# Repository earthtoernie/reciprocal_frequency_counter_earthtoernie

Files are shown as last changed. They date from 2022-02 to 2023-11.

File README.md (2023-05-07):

# Reciprocal frequency counter for Raspberry pi pico

Shield: [][cc-by-sa]

This work is licensed under a
[Creative Commons Attribution-ShareAlike 4.0 International License][cc-by-sa].

[][cc-by-sa]

[cc-by-sa]: http://creativecommons.org/licenses/by-sa/4.0/
[cc-by-sa-image]: https://licensebuttons.net/l/by-sa/4.0/88x31.png
[cc-by-sa-shield]: https://img.shields.io/badge/License-CC%20BY--SA%204.0-lightgrey.svg

## Citation
[Rrciprocal frequency counter](https://forums.raspberrypi.com/viewtopic.php?t=306250)
 The guts of the "pio" code was copied from this thread, and slightly modified and translated from "micropython"
 Display stuff, and PCB is my own.

## Main project
[The counter](pico_display_oled/main.cpp)

## Circuit board
[kicad board](kicad_pico_counter_new)
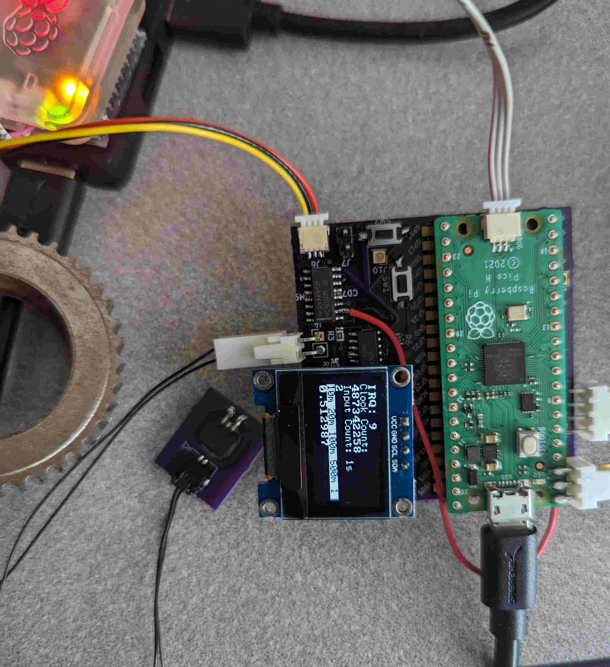
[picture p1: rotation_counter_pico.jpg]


## Background
- Wanted to make a speed sensor to detect gear teeth for some application. Did not need to use a "Reciprocal frequency counter" and / or such
a complicated "pio" setup, but decided to go down this route anyway.

- Picked a part from "Allegro microsystems" to do the sensing. There was no "Development board" available, but this should be just as good :)

- "ATS19480: Large Air Gap, GMR Speed Sensor IC for Gear Tooth Sensing" is the part. Should be available on Digikey or Mouser.

## Features
- Circuit board has a "driver" to read from a 2 terminal device. Window comparator added to translate discrete states of current, to 3.3 IO voltage.
This is for compatibility with GPIO on the pico board.

- Have had success using the sensor to read from the position 

- Button to change the window size

- Reset button (the pico board should have had this from the get go)

- Button to switch between sensor input, and input from 50ohm source (function generator)

## Brag
Was able to conveniently run from the 5V usb power source, with no additional boost converter.

## Awesome script to install sdk on Ubuntu 23.04
[install script](NOTES/install_raspberry_pico.sh) 

# Notes
Some other junk is included in this project (interfacing with other sensors), feel free to ignore. Also other "Scratch" projects included

sudo minicom -D /dev/ttyACM0 -b 115200  

Also examples from [pimoroni C examples](https://github.com/pimoroni/pimoroni-pico/tree/main/examples)  
how to setup IDE [Pico + cLion](https://forums.raspberrypi.com/viewtopic.php?t=310446)

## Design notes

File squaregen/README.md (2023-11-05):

do some stuff with [Pico board](https://github.com/Xinyuan-LilyGO/LILYGO-T-display-RP2040)

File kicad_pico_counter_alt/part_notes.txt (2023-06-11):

Parts:

IC's
1x, Mouser, TI, INA203AIDR, Unidir Msrmt Current Shunt Mon, Mouser 595-INA203AIDR
1x, Digikey, TI, TS5A63157DBVR, TS5A63157DBVR, IC SWITCH SPDT X 1 10OHM SOT23-6, 296-21194-1-ND
1x, Digikey, Raspberry Pi, SC0917, RASPBERRY PI PICO H, 2648-SC0917-ND
1x, Digikey, Microchip, 24AA64T-E/OT, IC EEPROM 64KBIT I2C SOT23-5m, 24AA64T-E/OTCT-ND
1x, Digikey, Nexperia, 74HC2G34GV 125, IC BUFFER NON-INVERT 6V 6TSOP, 1727-8398-1-ND
1x, Digikey, Allegro MicroSystems, ATS19580LSNBTN-FSNHPO-A, LARGE AIR GAP GMR TRANSMISSION, 620-ATS19580LSNBTN-FSNHPO-ADKR-ND

SMT connectors
1x, Digikey, JST, SM03B-SRSS-TB(LF)(SN), CONN HEADER SMD R/A 3POS 1MM, 455-1803-1-ND
1x, Digikey, JST, SM04B-SRSS-TB(LF)(SN), CONN HEADER SMD R/A 4POS 1MM, 455-1804-1-ND

RF connectors
1x, Digikey, Molex, 0733960320, SMB Connector Jack, SMB 50 OHM JACK R/A PCB, 900-0733960320-ND

thru hole connectors,
2x, Digikey, Samtec, SLW-120-01-F-S, CONN RCPT 20POS 0.1 GOLD PCB, SAM12857-ND
2x, Digikey, Molex, 0022122024, CONN HEADER R/A 2POS 2.54MM, WM2711-ND
1x, Digiket, Molex, 0022122044, CONN HEADER R/A 4POS 2.54MM, WM2713-ND
1x, Digikey, Sullins Connector Solutions, PPPC041LFBN-RC, CONN HDR 4POS 0.1 GOLD PCB, S7037-ND

alterntive
1x, Digikey, Adafruit, 5585, SHORT SOCKET HEADERS FOR RASPBER, 1528-5585-ND

Switches
4x, Digikey, C&K, PTS636 SL50 SMTR LFS, TACT 6.0 X 3.5, 5.0 MM H 130GF, CKN12313-1-ND
1x, Digikey, C&K, RS-282G05A3-SM RT, SWITCH TACTILE SPST-NO 0.05A 12V, CKN10384CT-ND

passives
2x, Digikey, Walsin Technology Corporation, WR08X332 JTL, RES 3.3K OHM 5% 1/8W 0805, 1292-WR08X332JTLCT-ND
1x, Digikey, Stackpole Electronics Inc, RNCP0805FTD49R9, RES 49.9 OHM 1% 1/4W 0805, RNCP0805FTD49R9CT-ND
1x, Digikey, Stackpole Electronics Inc, RMCF0805ZT0R00, RES 0 OHM JUMPER 1/8W 0805, RMCF0805ZT0R00CT-ND
1x, Digikey, Delta Electronics/Cyntec, RLT1220-F-5R00-FNH, RES SMD 5 OHM 1% 1/3W 0805, 2037-RLT1220-F-5R00-FNHCT-ND
1x, Digikey, TDK Corporation, CGA4J3X7R1A335K125AB, CAP CER 3.3UF 10V X7R 0805,445-12729-1-ND
1x, Digikey, Samsung Electro-Mechanics, CL21B105KOFNNNE, CAP CER 1UF 16V X7R 0805, 1276-1026-1-ND
1x, Digikey, Samsung Electro-Mechanics, CL21B103KBANNNC, CAP CER 10000PF 50V X7R 0805, 1276-1015-1-ND

misc connectors and parts
Digikey, Molex, 5037630291, CONN HEADER SMD R/A 2POS 1MM, WM10654CT-ND
Digikey, Molex, 0151310206, CABLE-ASSY PICOLOCK 2 CIRCUIT 60, WM16704-ND
Digikey, Harwin Inc, M20-9993645, CONN HEADER VERT 36POS 2.54MM, 952-2272-ND
Digikey, Harwin Inc, M20-9773642, CONN HEADER VERT 36POS 2.54MM, 952-2848-ND
Digikey, Molex, 0008650816, CONN 22-30AWG CRIMP GOLD, WM6391-ND,
Digikey, Molex, 0022013047, CONN RCPT HSG 4POS 2.54MM, WM2002-ND
Digikey, Molex, 0022013027, CONN RCPT HSG 2POS 2.54MM, 900-0022013027-ND
Digikey, Keystone Electronics, 5007, PC TEST POINT COMPACT WHITE, 36-5007-ND
Digikey, Taoglas Limited, CAB.0101, CBL ASSY SMA-SMB JACK-PLG 3.937", 931-1104-ND
Digikey, CNC Tech, 10368-28-1-0500-002-1-TS, HOOK-UP STRND 28AWG 300V WHT 25', CN390W-25-ND
Digikey, Sullins Connector Solutions, PRPC040SACN-RC, CONN HEADER VERT 40POS 2.54MM, S1131EC-40-ND
Digikey, Molex, 0022012091, CONN RCPT HSG 9POS 2.54MM, 23-0022012091-ND

tools
1x, Digikey, Apex Tool Group, T0050104199, RTP 004 S TIP CHISEL 0.4X0.2, 72-T0050104199-ND
1x, Digikey, Apex Tool Group, T0052922699, WXPP HANDPIECE FOR RTP TIP, 72-T0052922699-ND
1x, Digikey, Apex Tool Group, WX2N, SOLDERING STATION 200W 2 CH, 120V WX2N-ND
1x, Digikey, Apex Tool Group, T0050105899, RTU 015 S MS TIP CHISEL 1.5X0.4, 72-T0050105899-ND
1x, Digikey, Apex Tool Group, T0052923099, WXUP MS HANDPIECE FOR RTU MS TIP, 72-T0052923099-ND
1x, Digikey, Molex, 0638170000, TOOL HAND STRIPPER 8-34AWG, WM9969-ND
1x, Digikey, Molex, 0638118200, TOOL HAND CRIMPER 22-30AWG SIDE, WM9019-ND

1x, Digikey, Jonard Tools, EX-2, TOOL EXTRACTOR IC DIP 24-40PIN, K158-ND (to remove pico from socket)

notes about parts

*for EEPROM:
Most "Microchip" parts set lower address bits to "don't care's" which is not desirable
need a  SOT-23-5 part where the address pins are set internally to "0" so use:

24AA64/24FC64/24LC64 (24AA64T-E/OT seems to be in stock frequently) or
24AA64F/24LC64F/24FC64F

only difference is write protect scheme, but write protect is not used anyway (tied to ground)

alternatively "SparkFun Qwiic EEPROM Breakout - 512Kbit" can be used, or no EEPROM chip (state not saved)

*for buffer / level converter:
Nexperia 74HC2G34GV,125 used because of small board size
TI CD74HC4050M96 also tested, but changed due to large board size

*for current sense / comparator, 
INA203AIDR, stocked at Mouser, but not Digikey
INA203AID also works (same thing) but seems to be even less stocked

molex connectors, board:
Molex 0022122024, CONN HEADER R/A 2POS 2.54MM, WM2711-ND

smb connector:
Molex 0733960320, SMB 50 OHM JACK R/A PCB, 900-0733960320-ND

JST connectors:

connectors for sensor:
Molex 5037630291 WM10654CT-ND
Molex 0151310206 WM16704-ND

tact switch:
C&K PTS636 SL50 SMTR LFS, CKN12313-1-ND

(use different reset switch)
https://www.digikey.com/en/products/detail/c-k/RS-282G05A3-SM-RT/2747190

IC switch:
TI TS5A63157DBVR, IC SWITCH SPDT X 1 10OHM SOT23-6, 296-21194-1-ND
https://www.digikey.com/en/products/detail/texas-instruments/TS5A63157DBVR/1216800

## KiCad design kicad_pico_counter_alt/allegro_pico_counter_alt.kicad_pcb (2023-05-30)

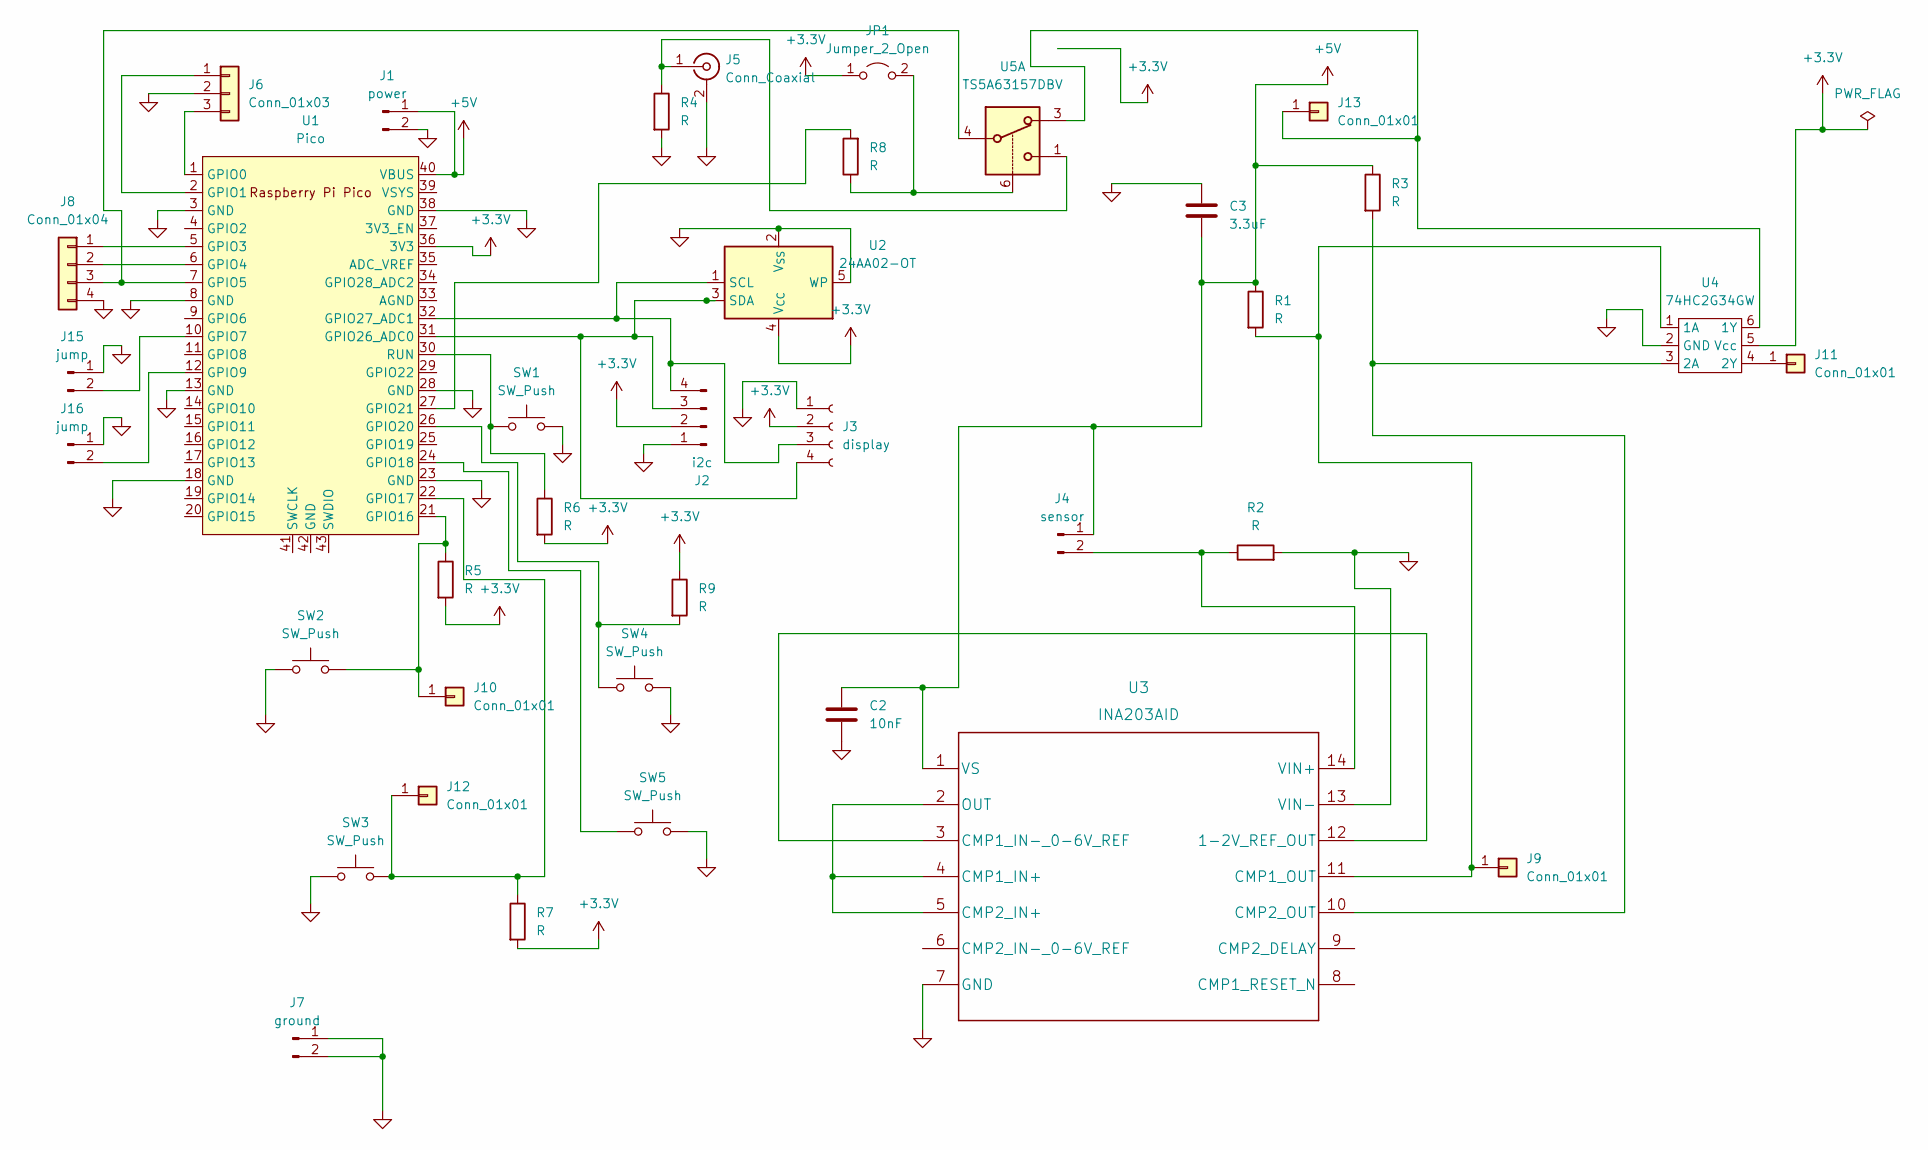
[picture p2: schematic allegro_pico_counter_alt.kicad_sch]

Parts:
C2: 10nF; C_0805_2012Metric
C3: 3.3uF; C_0805_2012Metric
J1: power; PinHeader_1x02_P2.54mm_Vertical
J2: i2c; JST_SH_SM04B-SRSS-TB_1x04-1MP_P1.00mm_Horizontal
J3: display; PinHeader_1x04_P2.54mm_Vertical
J4: sensor; PinHeader_1x02_P2.54mm_Vertical
J5: Conn_Coaxial; SMB_Jack_Vertical
J6: Conn_01x03; JST_SH_SM03B-SRSS-TB_1x03-1MP_P1.00mm_Horizontal
J7: ground; PinHeader_1x02_P2.54mm_Vertical
J8: Conn_01x04; PinHeader_1x04_P2.54mm_Vertical
J9, J10, J11, J12, J13: Conn_01x01; PinHeader_1x01_P2.54mm_Vertical
J15, J16: jump; PinHeader_1x02_P2.54mm_Vertical
JP1: Jumper_2_Open; PinHeader_1x02_P2.54mm_Vertical
R1, R2, R3, R4, R5, R6, R7, R8, R9: R; R_0805_2012Metric
SW1, SW2, SW3, SW4, SW5: SW_Push; SW_SPST_CK_RS282G05A3
U1: Pico; RPi_Pico_SMD_TH
U2: 24AA02-OT; SOT-23-5
U3: INA203AID
U4: 74HC2G34GW; SOT-363_SC-70-6_Handsoldering
U5: TS5A63157DBV; SOT-23-6

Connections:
+3.3V: J2.2, J3.2, JP1.1 (A), R5.2, R6.2, R7.2, R9.1, U1.36 (3V3), U2.4 (V_{CC}), U4.5 (Vcc); also elsewhere on the board
+5V: C2.1, C3.2, J1.1, J4.1, R1.1, R3.1, U1.40 (VBUS), U3.1 (VS)
GND: C2.2, C3.1, J1.2, J2.1, J3.1, J5.2 (Ext), J6.2, J7.1, J7.2, J8.4, J15.1, J16.1, R2.2, R4.2, SW1.2, SW2.1, SW3.1, SW4.2, SW5.2, U1.3 (GND), U1.8 (GND), U1.13 (GND), U1.18 (GND), U1.23 (GND), U1.28 (GND), U1.38 (GND), U2.2 (V_{SS}), U2.5 (WP), U3.7 (GND), U3.13 (VIN-), U4.2 (GND)
unnamed 3: J2.3, J3.4, U1.31 (GPIO26_ADC0), U2.3 (SDA); also elsewhere on the board
unnamed 4: J2.4, J3.3, U1.32 (GPIO27_ADC1), U2.1 (SCL); also elsewhere on the board
unnamed: J4.2, R2.1, U3.14 (VIN+)
unnamed: J5.1 (In), R4.1, U5.1
unnamed: J6.1, U1.2 (GPIO1)
unnamed: J6.3, U1.1 (GPIO0)
unnamed: J8.1, U1.5 (GPIO3)
unnamed: J8.2, U1.6 (GPIO4)
unnamed: J8.3, U1.7 (GPIO5), U5.4
unnamed: J9.1, R1.2, U3.11 (CMP1_OUT), U4.1 (1A)
unnamed: J10.1, R5.1, SW2.2, U1.21 (GPIO16)
unnamed: J11.1, U4.4 (2Y)
unnamed: J12.1, R7.1, SW3.2, U1.22 (GPIO17)
unnamed: J13.1, U4.6 (1Y), U5.3
unnamed: J15.2, U1.10 (GPIO7)
unnamed: J16.2, U1.12 (GPIO9)
unnamed: JP1.2 (B), R8.1, U5.6
unnamed: SW5.1, U1.24 (GPIO18)
unnamed: R9.2, SW4.1, U1.26 (GPIO20)
unnamed: R8.2, U1.27 (GPIO21)
unnamed: R6.1, SW1.1, U1.30 (RUN)
unnamed: U3.3 (CMP1_IN-_0-6V_REF), U3.12 (1-2V_REF_OUT)
unnamed: U3.2 (OUT), U3.4 (CMP1_IN+), U3.5 (CMP2_IN+)
unnamed: R3.2, U3.10 (CMP2_OUT), U4.3 (2A)

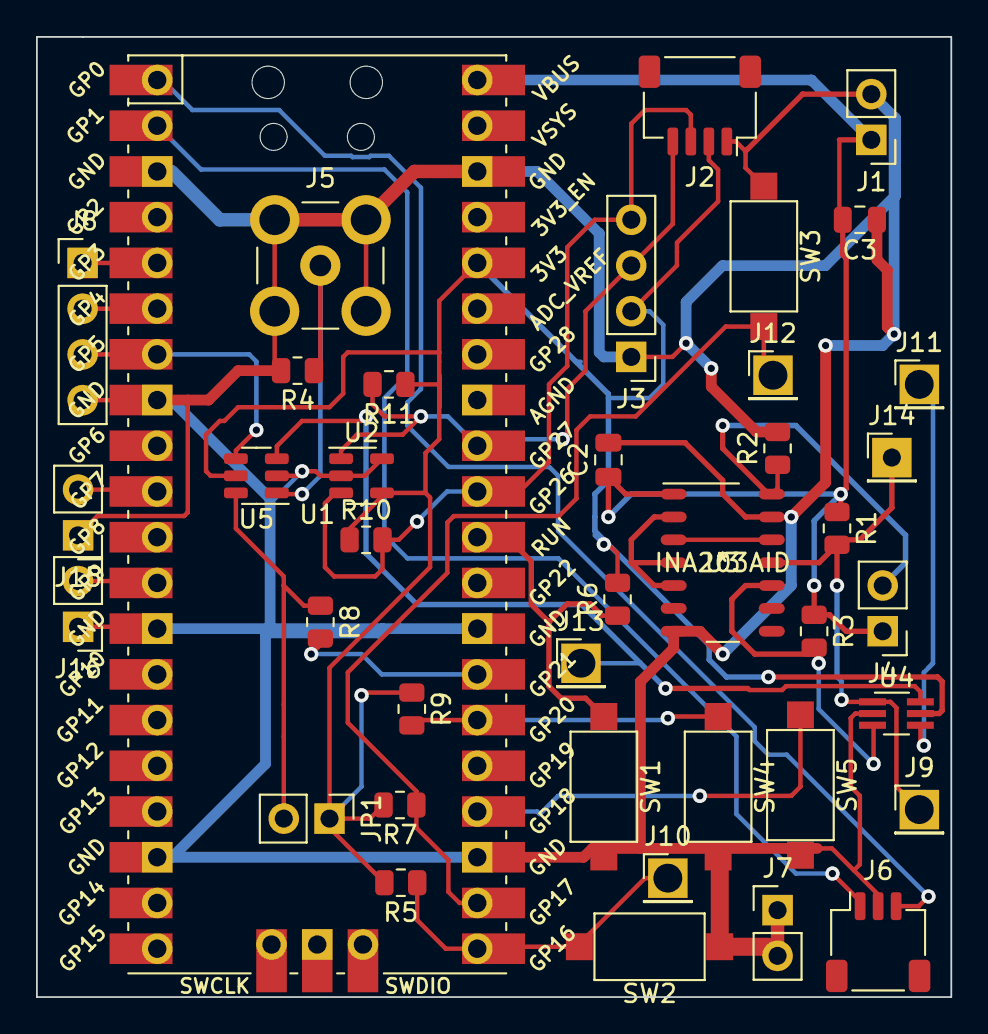
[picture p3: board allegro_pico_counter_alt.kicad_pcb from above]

Board: 2 copper layers, 50.8 x 53.3 mm, 40 parts (0 on the bottom side), 27 nets.

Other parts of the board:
J14: Conn_01x01; PinHeader_1x01_P2.54mm_Vertical
R10, R11: R; R_0805_2012Metric

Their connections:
+3.3V: R10.1, R11.1; also elsewhere on the board
unnamed 3: R10.2; also elsewhere on the board
unnamed 4: R11.2; also elsewhere on the board

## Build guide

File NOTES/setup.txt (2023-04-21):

install:

openocd
(sdk deps)
cmake gcc-arm-none-eabi gcc g++
(uart deps)
minicom

in pico folder:

main SDK:
git clone https://github.com/raspberrypi/pico-sdk.git
cd pico-sdk
git submodule update --init
cd ..

add to bashrc:
export PICO_SDK_PATH=/home/ernie/pico/pico-sdk
export PICO_EXAMPLES_PATH=/home/ernie/pico/pico-examples
export PICO_EXTRAS_PATH=/home/ernie/pico/pico-extras
export PICO_PLAYGROUND_PATH=/home/ernie/pico/pico-playground

git clone https://github.com/raspberrypi/pico-examples.git
git clone https://github.com/raspberrypi/pico-extras.git
git clone https://github.com/raspberrypi/pico-playground.git

inside of pico examples:
mkdir build
cd build
cmake ../ -DCMAKE_BUILD_TYPE=Debug

build some examples
cd blink
make
cd ..

cd hello_world
make
cd ..

MUST INSTALL... sudo apt install pkg-config
needed for picotool: libusb-1.0-0-dev
apt install 
build pictotool::
git clone https://github.com/raspberrypi/picotool.git
cd picotool
mkdir build
cd build
cmake ../
make
sudo cp picotool /usr/local/bin/

=============
see https://datasheets.raspberrypi.com/pico/getting-started-with-pico.pdf

code --install-extension marus25.cortex-debug
code --install-extension ms-vscode.cmake-tools
code --install-extension ms-vscode.cpptools

now onto fixing:
statics/globals/functions may not be properly classified:
https://forums.raspberrypi.com/viewtopic.php?t=333146
to actually get to run in the debugger in vscode...
sudo apt install gdb-multiarch 
sudo apt update
sudo apt install binutils-multiarch
cd /usr/bin
ln -s /usr/bin/objdump objdump-multiarch
ln -s /usr/bin/nm nm-multiarch

make sure to install Ninja!
sudo apt install ninja-build

https://github.com/microsoft/vscode-cmake-tools/blob/main/docs/debug-launch.md

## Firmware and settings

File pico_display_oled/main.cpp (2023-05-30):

#include <cstring>
#include <hardware/irq.h>
#include <cstdio>
#include <string>
#include "pico/stdio.h"
#include "pico/multicore.h"
#include "hardware/pio.h"
#include "count.pio.h"
#include "ss_oled.hpp"

#define INPUT_PIN 5
#define GATE_PIN 4
#define PULSE_FIN_PIN 3

// Button pins
#define BUTTON_WINDOW_PIN_16 16
#define BUTTON_SOURCE_PIN_17 17

// output pins
#define LED_PIN 25
// #define EXT50_EN_PIN 12
#define EXT50_EN_PIN 21

// i2c stuff. oled stuff
#define PICO_DEFAULT_I2C 1
#define PICO_DEFAULT_I2C_SDA_PIN 26
#define PICO_DEFAULT_I2C_SCL_PIN 27
#define PICO_I2C i2c_default
#define I2C_SPEED 400000

#define OLED_WIDTH 128
#define OLED_HEIGHT 64

#define GATE_err 0
#define GATE_1s 1
#define GATE_10ms 16
#define GATE_20ms 17
#define GATE_100ms 18
#define GATE_500ms 19

// global refference to display
extern picoSSOLED myOled(OLED_128x64, 0x3c, 0, 0, PICO_I2C, PICO_DEFAULT_I2C_SDA_PIN, PICO_DEFAULT_I2C_SCL_PIN, I2C_SPEED);


// debounce control
unsigned long time_window_state_debounce = to_ms_since_boot(get_absolute_time());
unsigned long time_source_state_debounce = to_ms_since_boot(get_absolute_time());

const int delayTime = 300; // Delay for every push button may vary

// glbal state ow windows in inputs
int button_window_state; // 1 represents the smallest window
bool button_source_state;

void update_source_state(bool is_external)
{
    if (is_external == true)
    {
        myOled.write_string(0, 0, 1, (char *)"50 Ohm, Clock Count:", FONT_6x8, 0, 1);
    }
    else
    {
        myOled.write_string(0, 0, 1, (char *)"Sensor, Clock Count:", FONT_6x8, 0, 1);
    }
    gpio_put(EXT50_EN_PIN, is_external);
    button_source_state = is_external; // update global state
}

void source_state_changed_callback(uint gpio, uint32_t events)
{
    if (gpio == BUTTON_WINDOW_PIN_16){
        if ((to_ms_since_boot(get_absolute_time()) - time_window_state_debounce) > delayTime){
            time_window_state_debounce = to_ms_since_boot(get_absolute_time());
            printf("********** WINDOW button pressed! %u\n", gpio);

            // Interrupt function lines
            // TODO
        }
    } else if (gpio == BUTTON_SOURCE_PIN_17){
        if ((to_ms_since_boot(get_absolute_time()) - time_source_state_debounce) > delayTime){
            time_source_state_debounce = to_ms_since_boot(get_absolute_time());
            printf("********** SOURCE button pressed! %u\n", gpio);
            update_source_state(!button_source_state);
        }
    }
}

uint32_t max_count = 4294967295;// const((1 << 32) - 1), highest unsigned int


PIO sd_pio = pio0;
volatile bool update_flag = false;
uint32_t countTo = 125000000; // 1M
int set_pin = 0;
uint32_t data [2] = { 0, 0 };



//https://raspberrypi.github.io/pico-sdk-doxygen/group__hardware__irq.html
void isr()
{
    pio_interrupt_clear(pio0, 0);
    //irq_clear(PIO0_IRQ_0);

    printf("IRQ: ");

    if(!update_flag){
        pio_sm_put(sd_pio, 0, countTo);
        pio_sm_exec(sd_pio, 0, pio_encode_pull(false, false));
        //printf("irq: ");

        data[0] = pio_sm_get(sd_pio, 1);
        data[1] = pio_sm_get(sd_pio, 2);
        update_flag = true;
    }
//    pio_interrupt_clear(pio0, 0);
//    pio_interrupt_clear(pio0, 0);
//    irq_clear(PIO0_IRQ_0);
}

void init_sm(uint32_t freq) {
    gpio_init(INPUT_PIN);
    gpio_init(GATE_PIN);
    gpio_init(PULSE_FIN_PIN);
    gpio_set_dir(INPUT_PIN, GPIO_IN);
    gpio_set_dir(GATE_PIN, GPIO_OUT);
    gpio_set_dir(PULSE_FIN_PIN, GPIO_OUT);
    gpio_put(GATE_PIN, 1);
    gpio_put(PULSE_FIN_PIN, 1);


    // starts state machines.
    uint offset_gate_program = pio_add_program(sd_pio, &gate_program);
    uint offset_clock_count_program = pio_add_program(sd_pio, &clock_count_program);
    uint offset_pulse_count_program = pio_add_program(sd_pio, &pulse_count_program);

    gate_program_init(sd_pio, 0, offset_gate_program);
    pio_sm_put_blocking(sd_pio, 0, freq);
    pio_sm_exec(sd_pio, 0, pio_encode_pull(false, false));

    clock_count_program_init(sd_pio, 1, offset_clock_count_program);
    pio_sm_put(sd_pio, 1, max_count);
    pio_sm_exec(sd_pio, 1, pio_encode_pull(false, false));
//
    pulse_count_program_init(sd_pio, 2, offset_pulse_count_program);
    pio_sm_put(sd_pio, 2, max_count-1);
    pio_sm_exec(sd_pio, 2, pio_encode_pull(false, false));

    irq_set_exclusive_handler(PIO0_IRQ_0, isr);
    irq_set_enabled(PIO0_IRQ_0, true);
    pio_set_irq0_source_enabled(sd_pio, pis_interrupt0, true);

    pio_sm_set_enabled(sd_pio, 1, true);
    pio_sm_set_enabled(sd_pio, 2, true);
    pio_sm_set_enabled(sd_pio, 0, true);

}

void initOledDisplay(picoSSOLED myOled){
//    IRQ: 8
//    Clock count: 125124944
//    Input count: 1001
//    Frequency: 1000.002136
    myOled.fill(0,1);
    myOled.write_string(0,0,0,(char *)"IRQ: **********", FONT_8x8, 0, 1);
    myOled.write_string(0,0,1,(char *)"50 Ohm, Clock Count:", FONT_6x8, 0, 1);
    myOled.write_string(0,0,2,(char *)"**********", FONT_8x8, 0, 1);
    if(set_pin == GATE_10ms) myOled.write_string(0,0,3,(char *)"Input Count: 10ms", FONT_6x8, 0, 1);
    if(set_pin == GATE_20ms) myOled.write_string(0,0,3,(char *)"Input Count: 20ms", FONT_6x8, 0, 1);
    if(set_pin == GATE_100ms) myOled.write_string(0,0,3,(char *)"Input Count: 100ms", FONT_6x8, 0, 1);
    if(set_pin == GATE_500ms) myOled.write_string(0,0,3,(char *)"Input Count: 500ms", FONT_6x8, 0, 1);
    if(set_pin == GATE_1s) myOled.write_string(0,0,3,(char *)"Input Count: 1s", FONT_6x8, 0, 1);
    if(set_pin == GATE_err) myOled.write_string(0,0,3,(char *)"Input Count: err", FONT_6x8, 0, 1);

    myOled.write_string(0,0,4,(char *)"**********", FONT_8x8, 0, 1);
    myOled.write_string(0,0,5,(char *)"10m 20m 100m 500m 1 ", FONT_6x8, 1, 1);
    myOled.write_string(0,0,6,(char *)"***.******", FONT_8x8, 0, 1);
}

void updateOled(uint32_t irqCount, uint32_t clockCount, uint32_t pulseCount, picoSSOLED myOled) {
    float frequency = pulseCount * (125000208.6 / clockCount);

    std::string irqCountString = "IRQ: " + std::to_string(irqCount);
    std::string clockCountString = std::to_string(clockCount);
    std::string pulseCountString = std::to_string(pulseCount);
    std::string frequencyString = std::to_string(frequency);

    myOled.write_string(0,0,0,(char *)"IRQ:           ", FONT_8x8, 0, 1);
    myOled.write_string(0,0,0,(char *)irqCountString.c_str(), FONT_8x8, 0, 1);

    myOled.write_string(0,0,2,(char *)"            ", FONT_8x8, 0, 1);
    myOled.write_string(0,0,2,(char *)clockCountString.c_str(), FONT_8x8, 0, 1);

    myOled.write_string(0,0,4,(char *)"            ", FONT_8x8, 0, 1);
    myOled.write_string(0,0,4,(char *)pulseCountString.c_str(), FONT_8x8, 0, 1);
    myOled.write_string(0,0,6,(char *)"            ", FONT_8x8, 0, 1);
    myOled.write_string(0,0,6,(char *)frequencyString.c_str(), FONT_8x8, 0, 1);
}

void core1_interrupt_handler(){
    while (multicore_fifo_rvalid()){
        uint16_t raw = multicore_fifo_pop_blocking();
    }
    multicore_fifo_clear_irq();
}

void core1_entry(){
    // Configure core 1 interrupt
    multicore_fifo_clear_irq();
    irq_set_exclusive_handler(SIO_IRQ_PROC1, core1_interrupt_handler);
    irq_set_enabled(SIO_IRQ_PROC1, true);

}

//void count_handler(sm)
int main() {
    // minicom -D /dev/ttyACM0 -b 115200
    // python3 ./usr/lib/python3/dist-packages/serial/tools/miniterm.py - 115200
    // ctrl ]
    // https://forums.raspberrypi.com/viewtopic.php?t=316677
    // python3 -m serial.tools.list_ports -v
    // https://forums.raspberrypi.com/viewtopic.php?t=306876

    gpio_pull_up(GATE_10ms);
    gpio_pull_up(GATE_20ms);
    gpio_pull_up(GATE_100ms);
    gpio_pull_up(GATE_500ms);
    gpio_init(GATE_10ms);
    gpio_init(GATE_20ms);
    gpio_init(GATE_100ms);
    gpio_init(GATE_500ms);
    gpio_set_dir(GATE_10ms, GPIO_IN);
    gpio_set_dir(GATE_20ms, GPIO_IN);
    gpio_set_dir(GATE_100ms, GPIO_IN);
    gpio_set_dir(GATE_500ms, GPIO_IN);

    gpio_pull_up(2);
    gpio_set_dir(2, GPIO_OUT);
    gpio_put(2, 1);

    bool gate_10ms_set = !gpio_get(GATE_10ms);
    bool gate_20ms_set = !gpio_get(GATE_20ms);
    bool gate_100ms_set = !gpio_get(GATE_100ms);
    bool gate_500ms_set = !gpio_get(GATE_500ms);
    stdio_init_all();

    button_source_state = true;

    // start init of buttons
    // just to know when the board is on ... not related to debounce
    gpio_init(LED_PIN);
    gpio_set_dir(LED_PIN, GPIO_OUT);
    gpio_put(LED_PIN, button_source_state);
    
    gpio_init(EXT50_EN_PIN);
    gpio_set_dir(EXT50_EN_PIN, GPIO_OUT);
    gpio_put(EXT50_EN_PIN, button_source_state);

    gpio_init(BUTTON_SOURCE_PIN_17);
    gpio_set_dir(BUTTON_SOURCE_PIN_17, GPIO_IN);
    gpio_pull_up(BUTTON_SOURCE_PIN_17);


    gpio_init(BUTTON_WINDOW_PIN_16);
    gpio_set_dir(BUTTON_WINDOW_PIN_16, GPIO_IN);
    gpio_pull_up(BUTTON_WINDOW_PIN_16);


    // interrupt
    // todo, "gpio_set_irq_enabled_with_callback" is broken
    // see https://forums.raspberrypi.com/viewtopic.php?t=339227&sid=64b002dadef60993ff6d878310481399
    // see https://github.com/raspberrypi/pico-sdk/releases
    // https://www.embedded.com/interrupts-in-c/ (NVIC)
    gpio_set_irq_callback( &source_state_changed_callback);
    gpio_set_irq_enabled(BUTTON_SOURCE_PIN_17, GPIO_IRQ_EDGE_FALL, true);
    gpio_set_irq_enabled(BUTTON_WINDOW_PIN_16, GPIO_IRQ_EDGE_FALL, true);
    irq_set_enabled(IO_IRQ_BANK0, true);
    // really good link below
    // https://github.com/mattwach/battery_drainer/blob/f88038b2f77225b453396fcbacbfb2b05bb002b9/src/lib/debounce/debounce.h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


    //gpio_set_irq_callback(BUTTON_WINDOW_PIN_16, GPIO_IRQ_EDGE_FALL , true, &window_state_changed_callback);


    // end init of buttons

    int total_set = 0;
    if(gate_10ms_set) {set_pin = GATE_10ms; total_set++; countTo = 1250000;}
    if(gate_20ms_set) {set_pin = GATE_20ms; total_set++; countTo = 2500000;}
    if(gate_100ms_set) {set_pin = GATE_100ms; total_set++; countTo = 12500000;}
    if(gate_500ms_set) {set_pin = GATE_500ms; total_set++; countTo = 62500000;}
    if(total_set > 1) {set_pin = GATE_err;}
    if(total_set == 0) {set_pin = GATE_1s;}



    printf("hello world!\n");
//    printf("%s %s %s %s \n" , gate_10ms_set?"true":"false", gate_20ms_set?"true":"false", gate_100ms_set?"true":"false", gate_500ms_set?"true":"false");
//    printf("set pin: %i \n", set_pin);

    int rc;
    //picoSSOLED myOled(OLED_128x64, 0x3c, 0, 0, PICO_I2C, PICO_DEFAULT_I2C_SDA_PIN, PICO_DEFAULT_I2C_SCL_PIN, I2C_SPEED);
    rc = myOled.init();
    // pio stuff
    init_sm(125000000);
    uint32_t i = 0;

//    multicore_launch_core1(core1_entry);
//    multicore_fifo_push_blocking(0);
    initOledDisplay(myOled);
    //updateOled(i, 1234567898, 42, myOled);
//    demoLoop(myOled, rc);


    while (true) {
        if (update_flag == true) {
            uint32_t clock_count = 2 * (max_count - data[0] + 1);
            uint32_t pulse_count = max_count - data[1];
            float frequency = pulse_count * (125000208.6 / clock_count);
            printf("%u %u %u\n", i, data[0], data[1]);
//            printf("d_0: %u\n", data[0]);
//            printf("d_1: %u\n", data[1]);
            printf("Clock count: %u\n", clock_count);
            printf("Input count: %u\n", pulse_count);
            printf("Frequency: %f\n", frequency);
            updateOled(i, clock_count, pulse_count, myOled);

            i++;
            update_flag = false;
        }
    }

}

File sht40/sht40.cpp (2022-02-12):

/**
 * Copyright (c) 2020 Raspberry Pi (Trading) Ltd.
 *
 * SPDX-License-Identifier: BSD-3-Clause
 */
#define PICO_DEFAULT_I2C 1
#define PICO_DEFAULT_I2C_SDA_PIN 26
#define PICO_DEFAULT_I2C_SCL_PIN 27


#include <stdio.h>
#include <pico/binary_info/code.h>
#include "pico/stdlib.h"
#include "hardware/i2c.h"

// mcp9808_i2c.c
//

static const uint8_t SHT_40_ADDRESS = 0x44;

int reg_write(i2c_inst_t *i2c,
              const uint addr,
              const uint8_t reg,
              uint8_t *buf,
              const uint8_t nbytes);

int reg_read(i2c_inst_t *i2c,
             const uint addr,
             const uint8_t reg,
             uint8_t *buf,
             const uint8_t nbytes);

// Write 1 byte to the specified register
int reg_write(i2c_inst_t *i2c,
              const uint addr,
              const uint8_t reg,
              uint8_t *buf,
              const uint8_t nbytes) {
    int num_bytes_read = 0;
    uint8_t msg[nbytes + 1];

    // Check to make sure caller is sending 1 or more bytes
    if (nbytes < 1) {
        return 0;
    }

    // Append register address to front of data packet
    msg[0] = reg;
    for (int i = 0; i < nbytes; i++) {
        msg[i + 1] = buf[i];
    }

    // Write data to register(s) over I2C
    i2c_write_blocking(i2c, addr, msg, (nbytes + 1), false);

    return num_bytes_read;
}
int main() {
    stdio_init_all();
    i2c_init(i2c_default, 400 * 1000);
    gpio_set_function(PICO_DEFAULT_I2C_SDA_PIN, GPIO_FUNC_I2C);
    gpio_set_function(PICO_DEFAULT_I2C_SCL_PIN, GPIO_FUNC_I2C);
    gpio_pull_up(PICO_DEFAULT_I2C_SDA_PIN);
    gpio_pull_up(PICO_DEFAULT_I2C_SCL_PIN);
    // Make the I2C pins available to picotool
//    bi_decl(bi_2pins_with_func(PICO_DEFAULT_I2C_SDA_PIN, PICO_DEFAULT_I2C_SCL_PIN, GPIO_FUNC_I2C));

    uint8_t msg1[2];
    msg1[0] = 0x94;
    i2c_write_blocking(i2c_default, SHT_40_ADDRESS, msg1, 1, false);
    sleep_ms(10);

    uint8_t msg2[2];
    msg2[0] = 0xFD;
    i2c_write_blocking(i2c_default, SHT_40_ADDRESS, msg2, 1, false);
    sleep_ms(10);

    uint8_t msg3[6];
    i2c_read_blocking(i2c_default, SHT_40_ADDRESS, msg3, 6, false);

    while (true) {

        uint8_t msg1[2];
        msg1[0] = 0x94;
        i2c_write_blocking(i2c_default, SHT_40_ADDRESS, msg1, 1, false);
        sleep_ms(10);

        uint8_t msg2[2];
        msg2[0] = 0xFD;
        i2c_write_blocking(i2c_default, SHT_40_ADDRESS, msg2, 1, false);
        sleep_ms(10);

        uint8_t rx_bytes[6];
        i2c_read_blocking(i2c_default, SHT_40_ADDRESS, rx_bytes, 6, false);

        uint16_t t_ticks = rx_bytes[0] * 256 + rx_bytes[1];
        uint16_t rh_ticks = rx_bytes[3] * 256 + rx_bytes[4];
        uint8_t checksum_t = rx_bytes[2];
        uint8_t checksum_rh = rx_bytes[5];
        //uint16_t t_degC_uint = -45 + 175 * t_ticks/65535;
        float t_degC_float = -45 + 175 * (float)t_ticks/65535;
        float rh_pRH = -6 + 125 * (float)rh_ticks/65535;


        //printf("temp C: %u\n", (unsigned int)t_degC_uint);
        printf("temp C: %.2f\n", t_degC_float);
        printf("temp F: %.2f\n", (t_degC_float * (9.0/5.0))+32);
        printf("    rh: %.2f\n", rh_pRH);



        printf("Hello, sht40!\n");
        sleep_ms(500);
    }
    return 0;
}

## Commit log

2021-12-12 add pimoroni libraries and drivers
2021-12-12 get the pico-display working
2021-12-19 sht40 prints temp and rh
2022-01-10 make pwm demo set two pins, update counter stuff
2022-02-10 prints interesting pattern with some letters across pico display
2022-02-13 add new project to test pio interrupts
2022-02-13 interrupt program works
2022-02-13 clean up printing
2022-02-21 fix init of sm 2
    [demo.cpp]
2022-02-25 stub out pico oled program, (annd add empty lib) but has undefined reference to blinkForever()
2022-03-06 counter prints to oled
2023-05-07 update license, add pictures, update readme
    [allegro_pico_counter_new.kicad_pcb, allegro_pico_counter_new.kicad_sch]
2023-05-07 moreve a bunch of stuff
    [bme280_spi.fzz, bmp280_i2c.fzz, hello_7segment.fzz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]
2023-05-07 remove some more junk
    [microphone_adc.fzz]
2023-05-13 add switch stuff
2023-05-14 update kicad and gitignore
    [allegro_pico_counter_new.kicad_pcb, allegro_pico_counter_new.kicad_sch]
2023-05-14 work on switch logic for inputs
2023-05-14 update callback code , and pcb layout
    [allegro_pico_counter_new.kicad_pcb]
2023-05-16 update button function
2023-05-30 add new pcb and schematic version, and change a pin in the code
    [allegro_pico_counter_alt.kicad_pcb, allegro_pico_counter_alt.kicad_sch]

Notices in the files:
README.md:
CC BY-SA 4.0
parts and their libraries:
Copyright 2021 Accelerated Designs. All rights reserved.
